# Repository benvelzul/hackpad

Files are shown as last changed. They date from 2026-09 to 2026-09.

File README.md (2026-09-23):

# HACKPAD

This hackpad is a 4x4 that has a rotary encoder. 

ITs got 2 layers the first layer is like normal numpad while the second is for the mediaplayer and everything that needs shortcuts that a 65% keyborad doesnt have (my laptop doesnt have) 

My Schematic: 



My PCB: 



My case:



PCB and case: 



If u want to check my onshape here it is (sorry if its really messy): https://cad.onshape.com/documents/7955f6143054f35a25e47023/w/3cc283572c9fd03e1a13d1ab/e/2172772127661373bbc4b207 

## Firmware

I made the firmware with KMK firmware thingy. 

So i just coded it instead of using the QMK config.

## BOM
here is what u need to make my amazing hackpad
- 15x Cherry MX Switches
- 15x DSA Keycaps
- 16x 1N4148 DO-35 Diodes.
- 1x EC11 Rotary Encoder
- 1x XIAO RP2040
- 1x Case
-

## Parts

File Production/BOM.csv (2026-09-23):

Reference | Qty | Value | DNP | Exclude from BOM | Exclude from Board | Footprint | Datasheet
D1,D2,D3,D4,D5,D6,D7,D8,D9,D10,D11,D12,D13,D14,D15,D16 | 16 | 1N4148 |  |  |  | Diode_THT:D_DO-35_SOD27_P7.62mm_Horizontal | https://assets.nexperia.com/documents/data-sheet/1N4148_1N4448.pdf
SW1 | 1 | RotaryEncoder_Switch |  |  |  | Rotary_Encoder:RotaryEncoder_Alps_EC11E-Switch_Vertical_H20mm
SW2,SW3,SW4,SW5,SW6,SW7,SW8,SW9,SW10,SW11,SW12,SW13,SW14,SW15,SW16 | 15 | SW_Push |  |  |  | PCM_marbastlib-mx:SW_MX_1u
U1 | 1 | MOUDLE-SEEEDUINO-XIAO |  |  |  | hackclub_lib:XIAO-Generic-Hybrid-14P-2.54-21X17.8MM

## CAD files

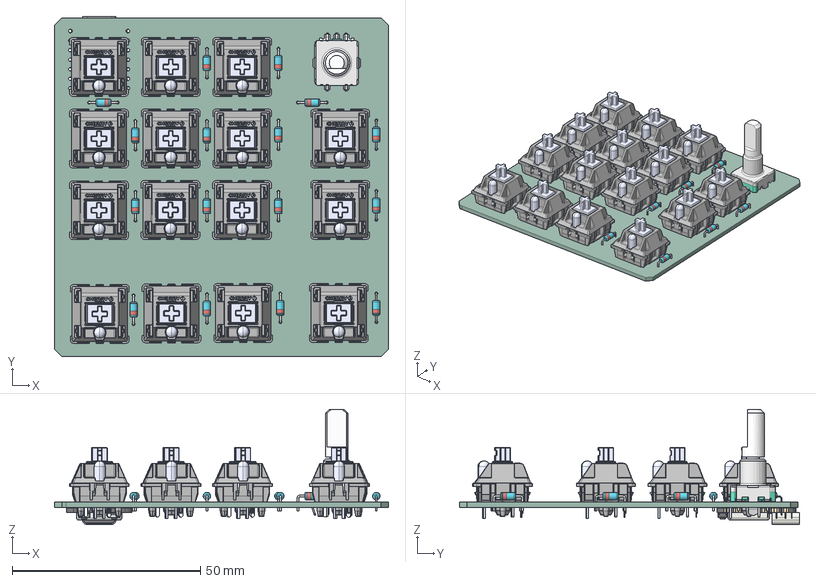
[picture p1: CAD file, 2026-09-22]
.step
88.8 x 90.4 x 30.6 mm
D_DO-35_SOD27_P7.62mm_Horizontal x 16
MX Series-Cherry Key x 15
(Unsaved)
type-c v2
smd_button v3
DOUT
DIN
VSS
VDD
smd_button v3(Mirror)
hackpad_PCB

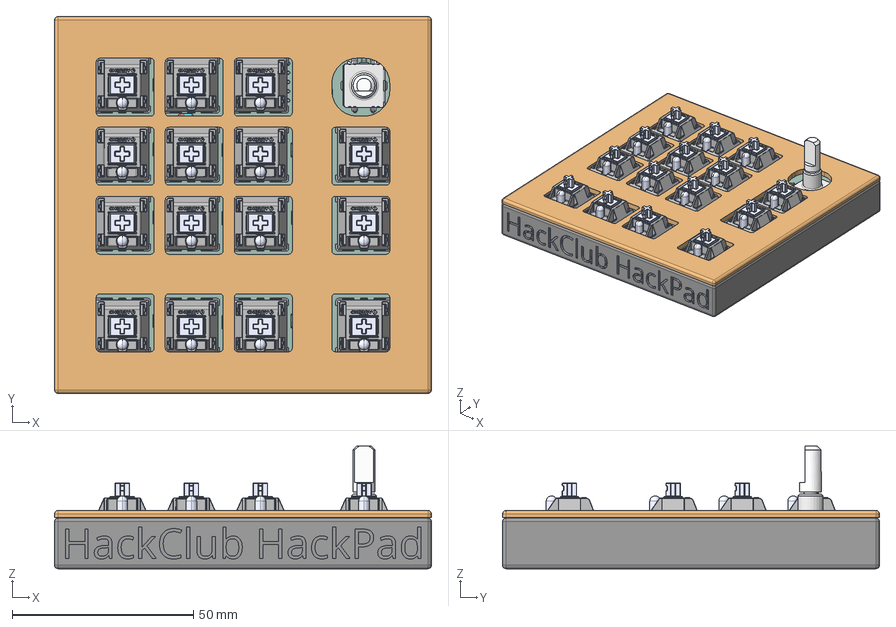
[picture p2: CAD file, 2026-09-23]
CAD/Hackpad cad.step
104.0 x 104.0 x 33.8 mm
hackpad_PCB
D_DO-35_SOD27_P7.62mm_Horizontal x 32
(Unsaved)
MX Series-Cherry Key x 150
smd_button v3
DOUT
VDD
DIN
VSS
smd_button v3(Mirror)
type-c v2 x 24

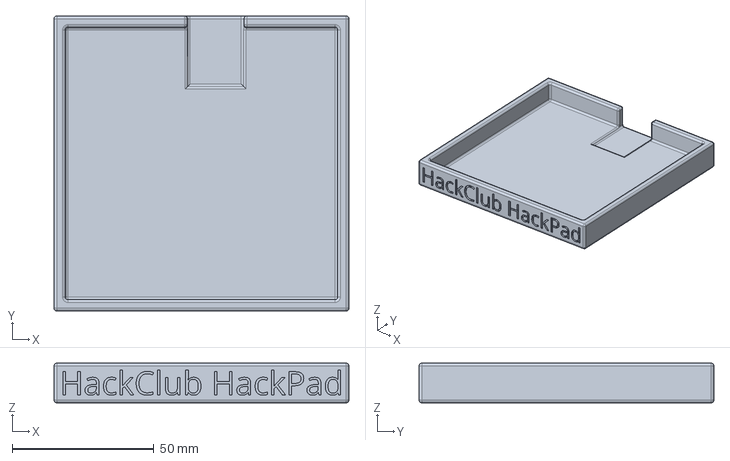
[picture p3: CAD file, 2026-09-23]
Production/Bottom.step
104.0 x 104.0 x 14.0 mm

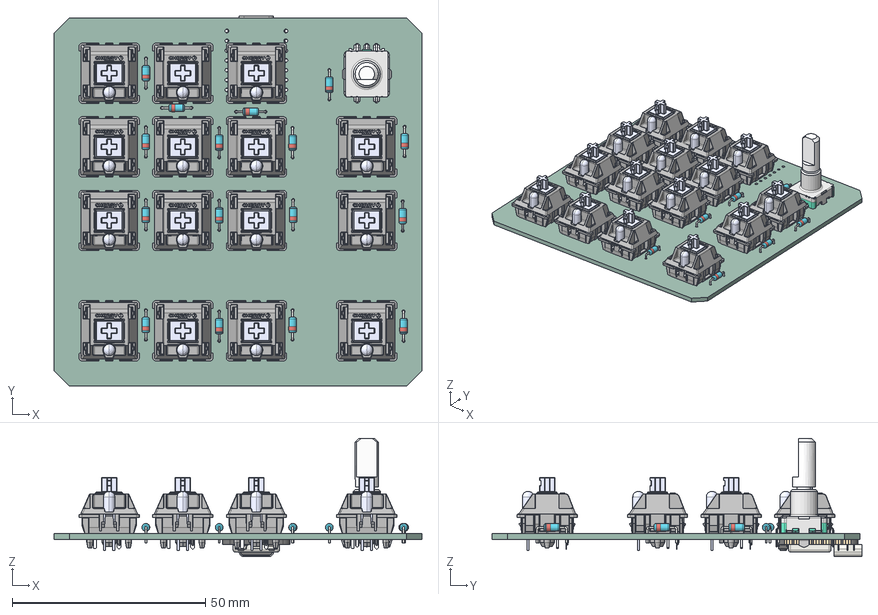
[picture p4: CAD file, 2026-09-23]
CAD/v2.step
95.3 x 95.8 x 30.6 mm
D_DO-35_SOD27_P7.62mm_Horizontal x 16
MX Series-Cherry Key x 15
(Unsaved)
type-c v2
smd_button v3
DOUT
DIN
VSS
VDD
smd_button v3(Mirror)
hackpad_PCB

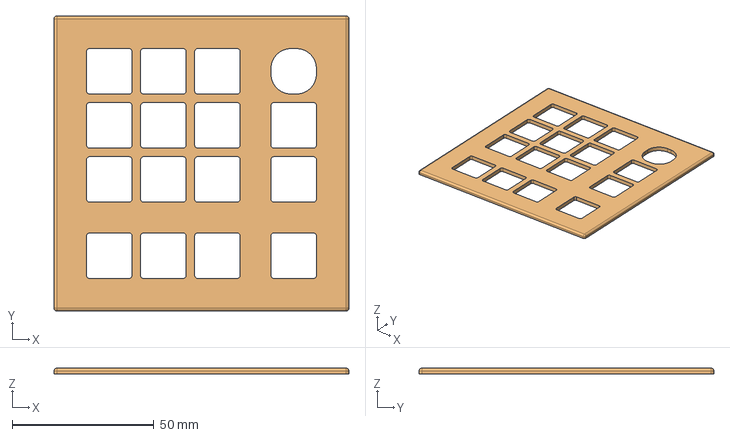
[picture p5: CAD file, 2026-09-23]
Production/Top.step
104.0 x 104.0 x 2.00 mm

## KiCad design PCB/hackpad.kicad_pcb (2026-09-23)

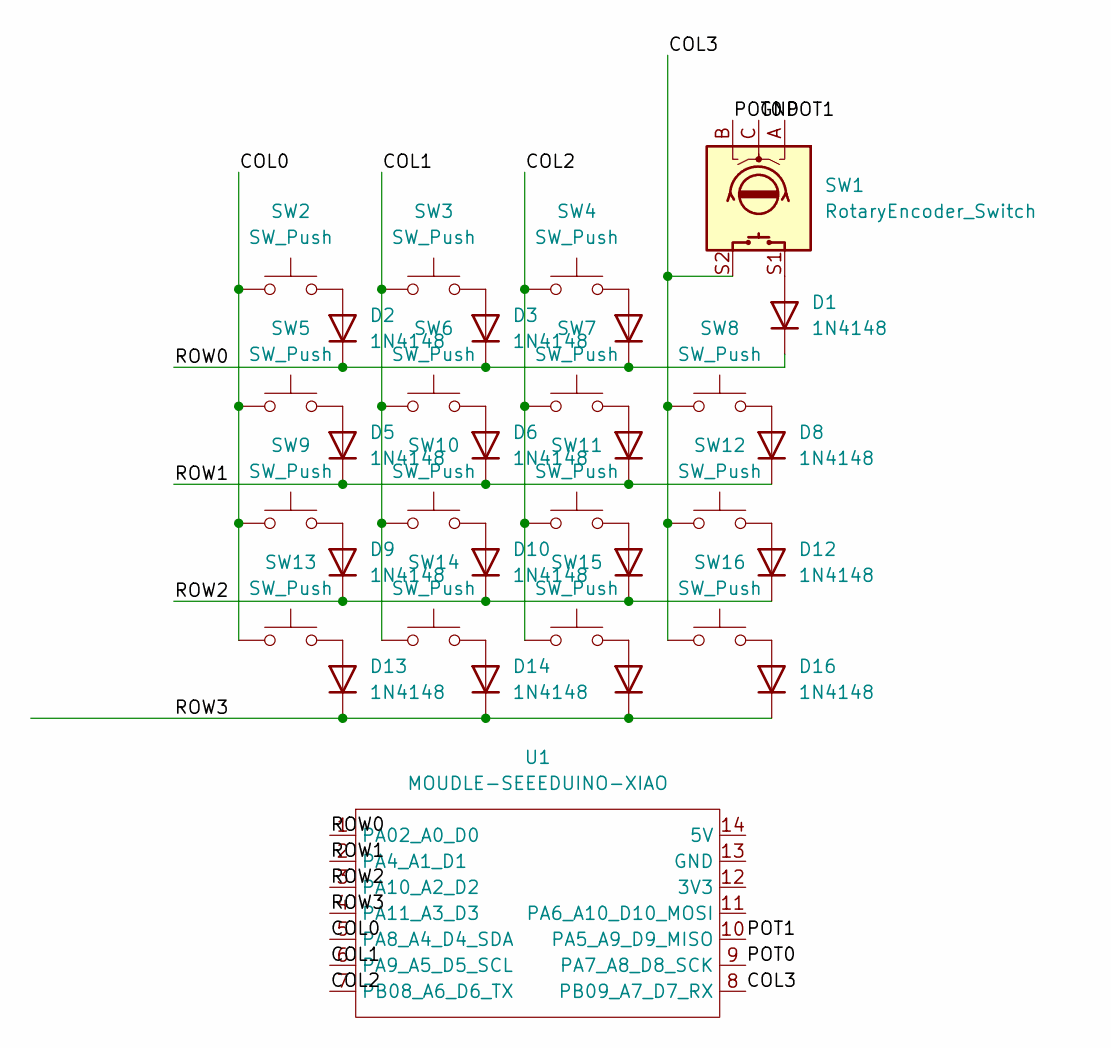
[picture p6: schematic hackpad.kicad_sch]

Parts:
D1, D2, D3, D4, D5, D6, D7, D8, D9, D10, D11, D12, D13, D14, D15, D16: 1N4148; D_DO-35_SOD27_P7.62mm_Horizontal
SW1: RotaryEncoder_Switch; RotaryEncoder_Alps_EC11E-Switch_Vertical_H20mm
SW2, SW3, SW4, SW5, SW6, SW7, SW8, SW9, SW10, SW11, SW12, SW13, SW14, SW15, SW16: SW_Push; SW_MX_1u
U1: MOUDLE-SEEEDUINO-XIAO; XIAO-Generic-Hybrid-14P-2.54-21X17.8MM

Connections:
/COL0: SW2.1, SW5.1, SW9.1, SW13.1, U1.5 (PA8_A4_D4_SDA)
/COL1: SW3.1, SW6.1, SW10.1, SW14.1, U1.6 (PA9_A5_D5_SCL)
/COL2: SW4.1, SW7.1, SW11.1, SW15.1, U1.7 (PB08_A6_D6_TX)
/COL3: SW1.S2, SW8.1, SW12.1, SW16.1, U1.8 (PB09_A7_D7_RX)
/GND: SW1.C
/POT0: SW1.B, U1.9 (PA7_A8_D8_SCK)
/POT1: SW1.A, U1.10 (PA5_A9_D9_MISO)
/ROW0: D1.1 (K), D2.1 (K), D3.1 (K), D4.1 (K), U1.1 (PA02_A0_D0)
/ROW1: D5.1 (K), D6.1 (K), D7.1 (K), D8.1 (K), U1.2 (PA4_A1_D1)
/ROW2: D9.1 (K), D10.1 (K), D11.1 (K), D12.1 (K), U1.3 (PA10_A2_D2)
/ROW3: D13.1 (K), D14.1 (K), D15.1 (K), D16.1 (K), U1.4 (PA11_A3_D3)
unnamed: D1.2 (A), SW1.S1
unnamed: D2.2 (A), SW2.2
unnamed: D3.2 (A), SW3.2
unnamed: D4.2 (A), SW4.2
unnamed: D5.2 (A), SW5.2
unnamed: D6.2 (A), SW6.2
unnamed: D7.2 (A), SW7.2
unnamed: D8.2 (A), SW8.2
unnamed: D9.2 (A), SW9.2
unnamed: D10.2 (A), SW10.2
unnamed: D11.2 (A), SW11.2
unnamed: D12.2 (A), SW12.2
unnamed: D13.2 (A), SW13.2
unnamed: D14.2 (A), SW14.2
unnamed: D15.2 (A), SW15.2
unnamed: D16.2 (A), SW16.2

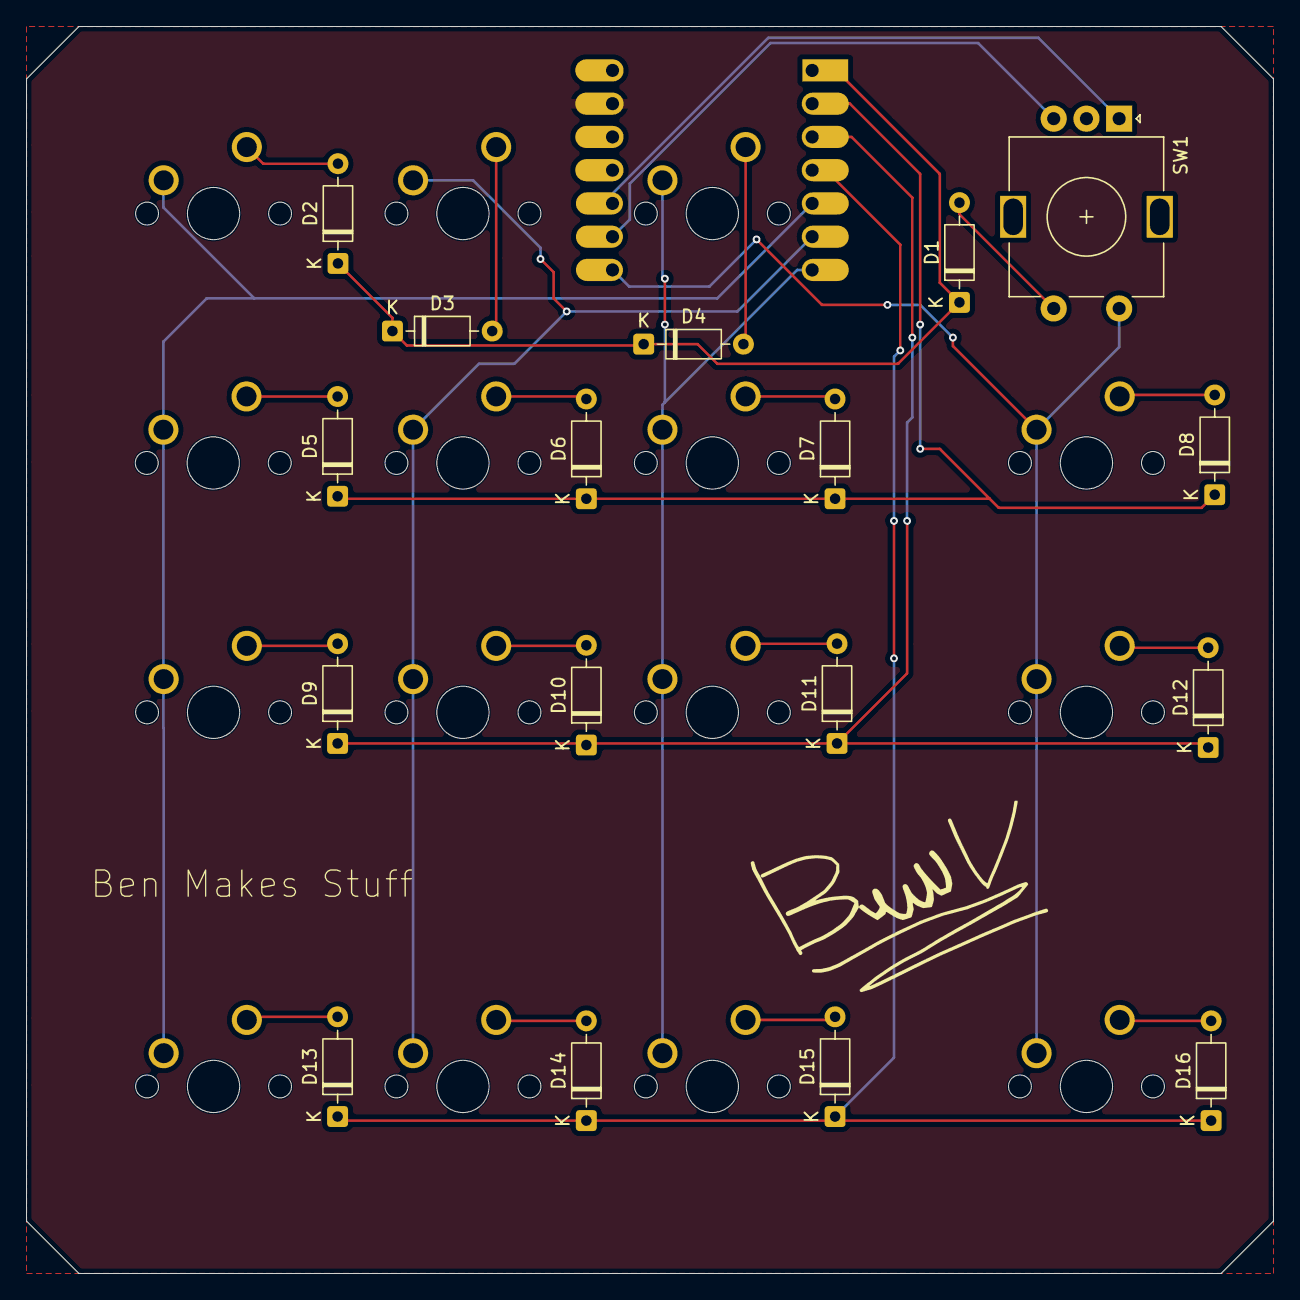
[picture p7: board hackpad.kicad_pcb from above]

Board: 2 copper layers, 95.3 x 95.2 mm, 34 parts (1 on the bottom side), 26 nets.

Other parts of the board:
 : LOGO

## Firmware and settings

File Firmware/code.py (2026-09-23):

import board
from kmk.kmk_keyboard import KMKKeyboard
from kmk.keys import KC
from kmk.scanners import DiodeOrientation

keyboard = KMKKeyboard()

keyboard.row_pins = (board.D0, board.D1, board.D2, board.D3) 
keyboard.col_pins = (board.D4, board.D5, board.D6, board.D7)

encoder_handler.pins = ((board.D8, board.D9, None, False),) 

keyboard.diode_orientation = DiodeOrientation.ROW2COL

keyboard.keymap = [
    [
        KC.N7,  KC.N8,  KC.N9,  KC.NO,         
        KC.N4,  KC.N5,  KC.N6,  KC.SLSH,    
        KC.N1,  KC.N2,  KC.N3,  KC.ASTR,   
        KC.N0,  KC.DOT, KC.ENT, KC.MO(1)
    ],
    [
        KC.TRNS, KC.TRNS, KC.TRNS, KC.NO, 
        KC.HOME, KC.UP,   KC.END,  KC.MINUS,
        KC.LEFT, KC.DOWN, KC.RGHT, KC.PLUS,     
        KC.BSPC, KC.TRNS, KC.TRNS, KC.TRNS 
    ]
]

encoder_handler.map = [
    ((KC.AUDIO_VOL_DOWN, KC.AUDIO_VOL_UP),),

    ((KC.MEDIA_PREV_TRACK, KC.MEDIA_NEXT_TRACK),)
]

if __name__ == '__main__':
    keyboard.go()

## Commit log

2026-07-28 Add KiCad schematic, project and prefs files
    Add hackpad.kicad_sch (complete schematic containing component symbols, instances, wires and junctions for push switches, diodes and a rotary encoder), populate hackpad.kicad_pro with project metadat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
    [hackpad.kicad_sch]
2026-08-01 Update KiCad schematic, project settings
    Add and update KiCad project and schematic data: populate net inspector columns; add extensive board design_settings (DRC rules, teardrop/tearing, track/tuning, pad/zone defaults); change annotation 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
    [hackpad.kicad_sch]
2026-09-16 Made some amazing progress and finished pcb
    [hackpad.kicad_pcb, hackpad.kicad_sch]
2026-09-22 I rediesinged it completly
    Sorry for my horrible spelling
    [.step, hackpad.kicad_pcb]
2026-09-23 exported the new version and did some stuff
    [v2.step]
2026-09-23 Reorganized all of the files
    [.step, hackpad.kicad_pcb, hackpad.kicad_sch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]
2026-09-23 Add KMK firmware and KiCad project
    Add Firmware/code.py: KMK (CircuitPython) keyboard configuration with row/col pins (D0–D7), encoder pins (D8–D9), diode orientation, two-layer keymap and encoder mappings, plus keyboard.go entrypoint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
2026-09-23 Add README for hackpad project
    Added detailed description of the hackpad project including images of the schematic, PCB, and case.
2026-09-23 gerber files done
    [hackpad-B_Cu.gbr, hackpad-B_Mask.gbr, hackpad-B_Paste.gbr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]
2026-09-23 Final cads
    [Bottom.step, Hackpad cad.step, Top.step]
2026-09-23 BOM done
    [BOM.csv]
